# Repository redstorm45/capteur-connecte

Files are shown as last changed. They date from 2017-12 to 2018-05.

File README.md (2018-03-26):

# Introduction

Code arduino et python du projet de capteur connecté.<br/>
Il est fait pour utilisation avec un ESP8266 (ESP-01), mais est sûrement utilisable pour d'autres modèles d'ESP.<br/>
Il est aussi fait pour utiliser un capteur Dallas DS18B20, communiquant avec le protocole One-Wire.

## Librairies

Le programme utilise les librairies suivantes:
- [DallasTemperature](https://github.com/milesburton/Arduino-Temperature-Control-Library)
- [NTPClient](https://github.com/arduino-libraries/NTPClient)
- OneWire
- [PubSubClient](https://github.com/knolleary/pubsubclient)

# Vue générale

## Architecture des transferts de données

Les données provennant du capteur sont captées par le programme à travers la bibliothèque OneWire, et converties en nombre à virgule flottante par la bibliothèque DallasTemperature.<br/>
À la réception, les données sont datés à l'aide de la bibliothèque NTPClient, et stockées dans un tampon temporaire avant envoi.<br/>
À interval fixe, le programme tente de vider tout le tampon de mesures, par des envois successifs à l'aide de MQTT, par la bibliothèque PubSubClient. Néanmoins, afin de ne pas trop impacter les prises de mesures, il ne s'effectue qu'un envoi par boucle principale, alors que cette même boucle vérifie à chaque fois s'il faut prendre une mesure, et fait fonctionner la pile TCP de l'ESP8266 au besoin.

## Modes de fonctionnement

## Configuration

En haut du programme sont définies les différentes constantes et variables utilisées pour le projet,
ainsi que les options de configuration.

### Constantes

Ces constantes permettent de définir les différents délais ainsi que les interfaces du programme, afin de pouvoir le régler selon l'application voulue.

| Nom | Unité | Fonction |
|---|---|---|
| PIN_CAPTEUR | N/A | Identifiant du pin sur lequel est connecté le capteur Dallas DS18B20 |
| DELAI\_MESURE | ms | Délai entre chaque mesure en fonctionnement normal |
| DELAI\_MESURE\_ECRASANT | ms | Délai entre chaque mesure en fonctionnement dégradé |
| DELAI\_MESURE\_CONVERSION  | ms | Délai permettant au capteur de réaliser sa mesure, avant de la lui demander |
| DELAI_ENVOI | ms | Délai entre chaque tentative d'envoi des données |
| DELAI_NTP | ms | Délai entre chaque synchronisation avec le serveur NTP |
| OFFSET_NTP | s | Décalage horaire entre l'heure NTP (UTC) et le fuseau actuel |
| LONGUEUR_BUFFER (buffer.h) | N/A | Défini la taille du buffer à utiliser, à choisir suivant la place restante pour les variables |

### Fonctionnement

Ces constantes permettent d'appliquer une compilation différente au programme, donc un fonctionnement différent.

| Nom | Fonction (si définie) |
|---|---|
| DEBUG | Ajoute des envois de messages par le port série sur divers événements |
| NTP_SERVER  | Utilise un serveur NTP, plutôt que d'attendre l'heure sous la forme d'un timestamp transmis par MQTT sur le channel "timestamp" |

# Programmation sur un ESP8266 (ESP-01)

## Position des pins

Voici l'arrangement des pins sur un ESP-01, vu de dessus (pins en dessous), avec l'antenne wi-fi sur la gauche.

| | |
|---|---|
| RX | VCC |
| GPIO0 | RST |
| GPIO2 | CH_PD |
| GND | TX |

## Connexion

On connecte les pins suivants sur un convertisseur USB <> Port série quelconque. Un Arduino peut remplir cette fonction, sans avoir à utiliser le sketch "Arduino as ISP", en fixant son pin de reset à la masse. Il ne semble pas nécessaire d'utiliser un convertisseur de niveau logique pour éviter d'abîmer la carte.

| Pin ESP8266 | Connecté à |
|---|---|
| RX | TX du convertisseur série |
| GPIO0 | pulldown pour programmer, pullup pour lancement normal |
| GPIO2 | pullup + capteur DS18B20 |
| GND | Masse |
| VCC | Alimentation +3.3V |
| RST | pullup |
| CH_PD | pullup |
| TX | RX du convertisseur série |

## Envoi du programme

Avant d'envoyer, on effectue une mise à la masse du pin de reset (RST), pour s'assurer que l'ESP n'est pas en train d'executer un programme.
On s'assure aussi d'avoir choisi la carte "Generic ESP8266 Module" dans l'IDE Arduino, pour lequel il faut avoir installé les bibliothèques de programmation pour l'ESP dans le gestionnaire de cartes. On vérifie enfin que le port série choisi est valide. Finalement, on peut envoyer le programme à l'aide du bouton "téléverser".

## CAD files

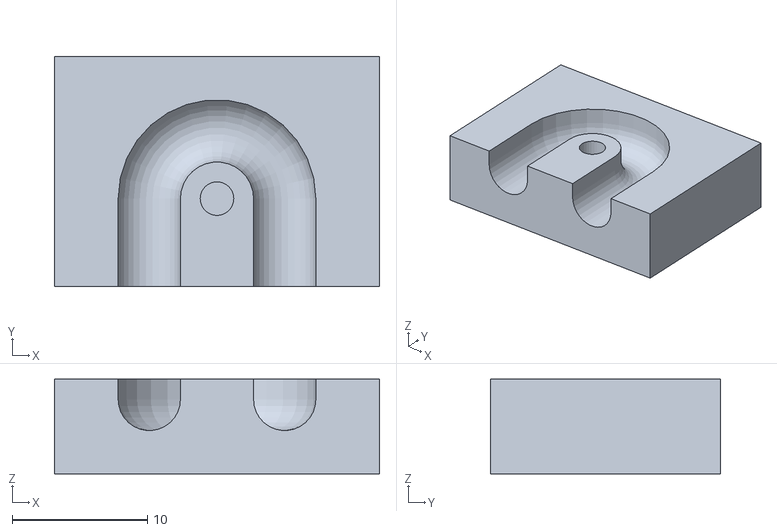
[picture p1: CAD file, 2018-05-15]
3d_temperature/serre_cable.stl
24.0 x 17.0 x 7.00

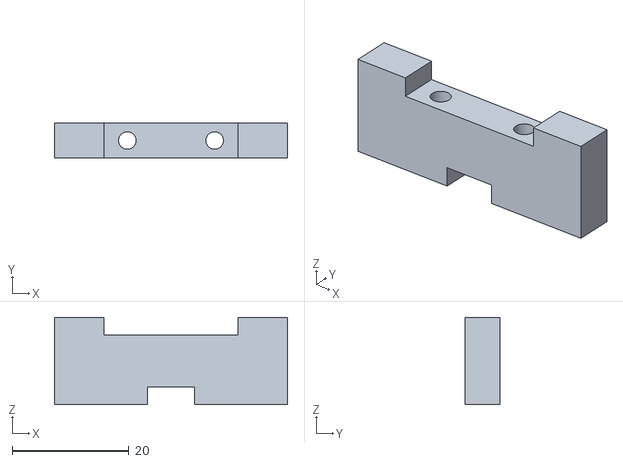
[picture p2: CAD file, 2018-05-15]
3d_temperature/support.stl
40.0 x 6.00 x 15.0

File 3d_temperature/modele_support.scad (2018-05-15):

module vis(){
    color([0.5, 0.5, 0.5])
    difference(){
        union(){
            translate([0, 0, -17.5]) cylinder(h=20, r=1.2, $fn=100);
            cylinder(h=2.5, r=2.5, $fn=100);
        }
        translate([0, 0, 2.5]) cube(size=[1.5, 10, 2], center=true);
    }
}
module ecrou(largeur, hauteur, di){
    color([0.5, 0.5, 0.5])
    difference(){
        
    }
}
module support(){
    color([0.93, 0.69, 0.2])
    difference(){
        translate([-20, -3, 0]) cube(size=[40, 6, 15]);
        translate([-4, -4, -1]) cube(size=[8, 8, 4]);
        translate([-7.5, 0, -1]) cylinder(h=17, r=1.5, $fn=100);
        translate([-11.5, -4, 12]) cube(size=[23, 8, 5]);
        translate([7.5, 0, -1]) cylinder(h=17, r=1.5, $fn=100);
    }
}
module forme_cable(){
    union(){
        translate([5, 0, 0]) circle(r=2.3);
        translate([5, 2.3, 0]) square(size=4.6, center=true);
    }
}
module serre_cable(){
    difference(){
        cube(size=[24, 17, 7], center=true);
        difference(){
            translate([0, -2, 2]) rotate_extrude() forme_cable();
            translate([0, -9.5, 0]) cube(size=[20, 15, 20], center=true);
        }
        translate([0, -1.99, 2]) rotate(90, [1, 0, 0]) linear_extrude(height=10) forme_cable();
        mirror([1, 0, 0]) translate([0, -1.99, 2]) rotate(90, [1, 0, 0]) linear_extrude(height=10) forme_cable();
        translate([0, -2, -1]) cylinder(r=1.24, h=20);
    }
}

translate([0, -50, 0]) serre_cable($fn=30);
support();
translate([7.5, 0, 12]) vis();
translate([-7.5, 0, 12]) vis();

//support();
//serre_cable($fn=30);

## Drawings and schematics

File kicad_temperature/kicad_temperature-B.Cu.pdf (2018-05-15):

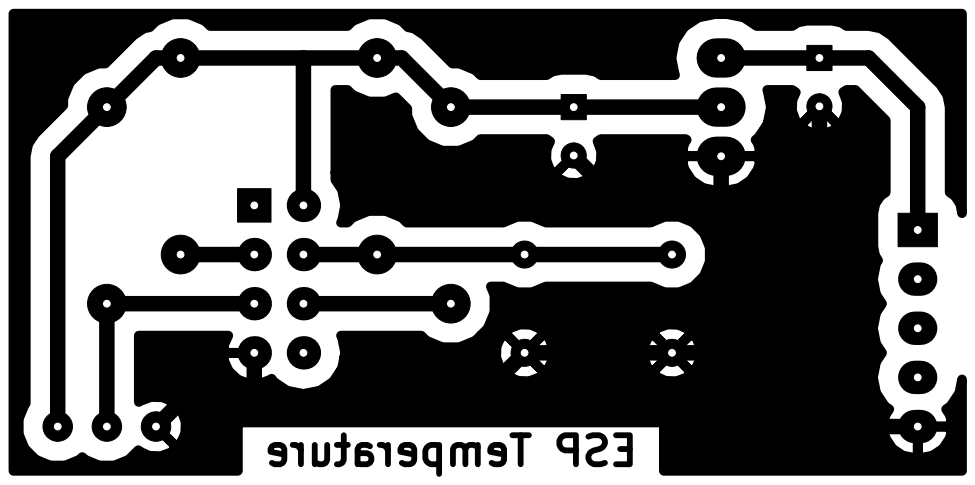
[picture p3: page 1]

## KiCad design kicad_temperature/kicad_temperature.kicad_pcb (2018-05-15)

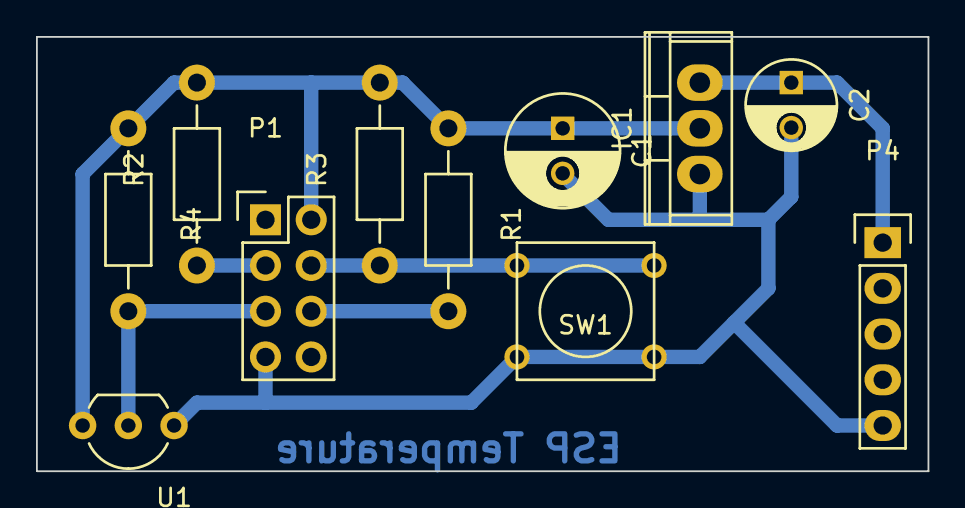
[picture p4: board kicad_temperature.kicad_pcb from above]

Board: 2 copper layers, 49.5 x 24.1 mm, 11 parts (0 on the bottom side), 7 nets.

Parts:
C1: 100µF; C_Radial_D6.3_L11.2_P2.5
C2: 10µF; C_Radial_D5_L11_P2.5
IC1: LM1117; TO-220
P1: CONN_02X04; Pin_Header_Straight_2x04
P4: CONN_01X05; Pin_Header_Straight_1x05
R1, R2, R3: 10k; Resistor_Horizontal_RM10mm
R4: 4.7k; Resistor_Horizontal_RM10mm
SW1: SW_PUSH; SW_PUSH_SMALL
U1: DS18B20; TO-92_Inline_Wide

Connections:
/CH_PD: P1.6, R1.2
/GPIO0: P1.3, R2.1
/GPIO2: P1.5, R4.2, U1.2
/RST: P1.4, R3.1, SW1.2
/VCC: C1.1, IC1.2, P1.2, R1.1, R2.2, R3.2, R4.1, U1.3
GND: C1.2, C2.2, IC1.1, P1.7, P4.5, SW1.1, U1.1
unnamed: C2.1, IC1.3, P4.1

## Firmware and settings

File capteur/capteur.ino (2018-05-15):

#include <ESP8266WiFi.h>
#include <WiFiUdp.h>
#include <OneWire.h>
#include <PubSubClient.h>      // https://github.com/knolleary/pubsubclient
#include <NTPClient.h>         // https://github.com/arduino-libraries/NTPClient
#include <DallasTemperature.h> // https://github.com/milesburton/Arduino-Temperature-Control-Library
#include "buffer.h"

/* *** Paramètres du programme *** */
// Pins
#define PIN_CAPTEUR  2
// Délai entre chaque mesure (ms)
#define DELAI_MESURE  30000
#define DELAI_MESURE_ECRASANT 300000
#define DELAI_MESURE_CONVERSION 800
#define DELAI_ENVOI 150000
#define DELAI_NTP 600000 // délai (ms)
#define OFFSET_NTP 0     // offset(s) 0: on veut le temps universel
// Mode débug
//#define DEBUG
#define NTP_SERVER

// Chaînes
const char* urlBrokerMQTT = "url";
const char* urlServeurNTP = "url";
const char* wifiSSID = "ssid";
const char* wifiMdp = "mdp";
const char* mqttUsername = "user";
const char* mqttTopic = "topic";

/* *** Objets pour les librairies *** */
// Connexion wi-fi
WiFiClient espClient;
// Connexion MQTT
PubSubClient clientMQTT(espClient);
// Lien UDP
#ifdef NTP_SERVER
 WiFiUDP ntpUDP;
 // Client NTP pour l'horodatage des données
 NTPClient timeClient(ntpUDP, urlServeurNTP, OFFSET_NTP, DELAI_NTP);
#else
 unsigned long lastTSUpdate;
 unsigned long currentTS;
#endif

// Instance OneWire pour le capteur de température
OneWire oneWire(PIN_CAPTEUR);

// Objet capteurs de températures
DallasTemperature capteurs(&oneWire);

// Objet pour l'addresse du capteur
DeviceAddress adresseCapteur;

/* *** Variables globales *** */
// wi-fi
bool etatWifi = false;
// buffer
Buffer buffer;
// mesures

unsigned long timerMesure;
unsigned long timerEnvoi;
bool lastMesureDone;

/* *** Définitions des fonctions *** */
void callback(char* topic, byte* payload, unsigned int length);
void setup();
void tickWifi();
String format(Mesure m);
Mesure* capte();
void loop();

/* *** Fonctions *** */
void callback(char* topic, byte* payload, unsigned int length) {
  #ifndef NTP_SERVER 
  if(strcmp(topic, "timestamp")==0){
    unsigned long newTS = 0;
    for(int i=0; i<length; i++){
      newTS = newTS*10 + payload[i] - int('0');
    }
    Serial.println("got ts:"+String(newTS));
    lastTSUpdate = millis();
    currentTS = newTS;
  }
  #endif
}

void setup() {
  // Initialiser la connexion wifi
  WiFi.begin(wifiSSID, wifiMdp);
  #ifdef DEBUG
    Serial.begin(9600);
    Serial.println("MAC Address:"+WiFi.macAddress());
  #endif
  while (WiFi.status() != WL_CONNECTED) {
    #ifdef DEBUG
      Serial.print(WiFi.status());
    #endif
    delay(500);
  }
  #ifdef DEBUG
    Serial.println("connecté");
    Serial.println(WiFi.localIP());
  #endif
  etatWifi = true;
  // NTP et MQTT déjà initialisés (objets créés)
  #ifdef NTP_SERVER
    timeClient.begin();
  #endif
  clientMQTT.setServer(urlBrokerMQTT, 1883);
  clientMQTT.setCallback(callback);
  delay(500);
  // Connexion au capteur
  capteurs.begin();
  capteurs.getAddress(adresseCapteur, 0);
  capteurs.setResolution(adresseCapteur, 12);
  timerMesure = millis() - DELAI_MESURE; // On force la première mesure
  timerEnvoi = millis();
  #ifdef DEBUG
    Serial.println("initialisé");
  #endif
}

void tickWifi(){
  if(etatWifi and WiFi.status() != WL_CONNECTED){
    // on vient de perde la connexion
    etatWifi = false;
  }else if(!etatWifi and WiFi.status() == WL_CONNECTED){
    etatWifi = true;
  }
}

String format(Mesure* m){
  return String(m->timestamp)+','+String(m->valeur);
}

Mesure* capte(){
  Mesure* m=new Mesure;
  #ifdef NTP_SERVER
    unsigned long TS = timeClient.getEpochTime();
  #else
    unsigned long TS = currentTS+(unsigned long)(millis()-lastTSUpdate)/1000;
  #endif
  (*m) = {.valeur = capteurs.getTempC(adresseCapteur), .timestamp = TS};
  return m;
}

void loop() {
  // Wi-fi
  tickWifi();
  // NTP
  #ifdef NTP_SERVER
    timeClient.update();
  #endif
  // MQTT
  if (WiFi.status() == WL_CONNECTED) {
    if (!clientMQTT.connected()) {
      #ifdef DEBUG
        Serial.println("reconnection au broker mqtt...");
      #endif
      if(clientMQTT.connect(mqttUsername)){
        clientMQTT.subscribe("timestamp");
        #ifdef DEBUG
          Serial.println("connecté au broker mqtt");
        #endif
      }
      #ifdef DEBUG
      else{
         Serial.println("connection au broker mqtt impossible");
      }
      #endif
    }
    else{
      clientMQTT.loop();
      if((millis()-timerEnvoi) >= DELAI_ENVOI){
        #ifdef DEBUG
          Serial.println("envoi possible");
        #endif
        if(buffer.disponible()){
          #ifdef DEBUG
            Serial.println("envoi!");
          #endif
          Mesure* m = buffer.popOldestData();
          String s=format(m);
          byte* data=(byte*)malloc(s.length()+1);
          s.getBytes(data, s.length()+1);
          clientMQTT.publish(mqttTopic, data, s.length()+1);
          free(data);
          delete m;
        }else{
          //Une fois que toutes les données ont été envoyée, on considere que c'est la fin du paquet.
          timerEnvoi = millis();
        }
      }
    }
  }
  // Capteur
  if((millis()-timerMesure) >= (buffer.isInLightMode()?DELAI_MESURE_ECRASANT:DELAI_MESURE)){
    timerMesure += buffer.isInLightMode()?DELAI_MESURE_ECRASANT:DELAI_MESURE;
    capteurs.requestTemperatures();
    lastMesureDone = true;
    #ifdef DEBUG
      Serial.println("request mesure");
    #endif
  }
  if(((millis()-timerMesure) >= DELAI_MESURE_CONVERSION) && lastMesureDone){
    lastMesureDone = false;
    Mesure* m=capte();
    buffer.addData(m);
    #ifdef DEBUG
      Serial.println("mesure!");
    #endif
  }
  // Fonctionnement de la pile TCP de l'ESP8266
  yield();
}

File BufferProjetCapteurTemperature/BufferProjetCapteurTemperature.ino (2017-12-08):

class Buffer{
  private:
    int size;
    int* list;
    int lastlastPosition;
    int firstlastPosition;
  public:
    Buffer(int n);
    void addData(int k);
    int *getLastData(int k);
    int *popLastData(int k);
};

Buffer::Buffer(int n){
  this->size = n; 
  this->lastlastPosition = 0;
  this->list = new int[n];
  
};


int *Buffer::getLastData(int k){
  if(k>this->size or k<=0){
    //Lancer une exception
    
  }else{
    int* dataArray= new int[k];
    for(int i=0;i++;i<k){
      dataArray[i] = list[this->size-k+i];
    };
    return *dataArray;
  }
  
};


void Buffer::addData(int k){
  this->list[this->lastPosition] = this->size;
  this->lastPosition += 1;
  this->lastPosition = this->lastPosition%this->size;
  return;
};

int *Buffer::popLastData(int k){
   if(k>this->size or k<=0){
    //Lancer une exception
    
  }else{
    int *dataArray = this::getLastData(k);
    this->firsData = (this->lastPosition-k)%this->size;
  }
}

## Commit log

2017-12-06 Ajout d'une base de code Arduino
2017-12-07 Reorganisateur de données en un tableau de bytes
2017-12-16 Génere des publications MQTT
2018-02-20 Changement de lib MQTT
2018-03-26 Séparation des modes de fonctionnement pour le NTP ou le timestamp par MQTT
2018-05-15 Modification des co,stantes de temps
2018-05-15 Circuit du capteur de temperature
    [kicad_temperature.kicad_pcb, kicad_temperature.sch]
2018-05-15 Modèles 3D du capteur de température
    [modele_support.scad, serre_cable.stl, support.stl]
